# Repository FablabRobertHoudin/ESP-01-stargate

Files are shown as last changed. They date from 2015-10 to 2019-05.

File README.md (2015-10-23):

# Horloge "stargate" avec bandeau LED (WS2812)

- Schéma Kicad

Attention à l'alimentation du ESP2866 qui nécessite + de 200mA au démarrage.

- Programme

Encore en développement.
Récupère l'heure par NTP (OK)
Une couleur peut être envoyée pour affichage ! - en cours, avec utilisation de PubNub

- Le modèle

Réalisé en médium 3mm.
La face avant avec les chiffres + 3 épaisseurs collées réalisées en 4 morceaux (asymétriques alternées)
Le bandeau (largeur 1cm) est colé à l'arrière de la face avant, sur les 3 épaisseurs arrière.

Initialement, je voulais le créer à partir d'une découpe d'un STL (crée à partir de openSCAD) par 123Make.
Mais les morceaux n'étaient pas compactés (voir le PDF)
J'ai donc arrangé les morceaux (tranchage dans openSCAD) à la main (stargate-pack.svg) pour optimiser la découpe du médium 3mm.

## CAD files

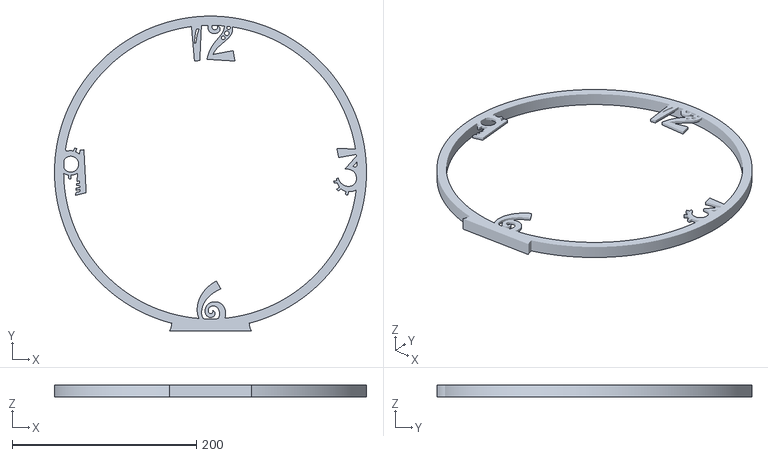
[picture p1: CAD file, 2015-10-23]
Modèle/Stargate.stl
338.3 x 341.3 x 13.0

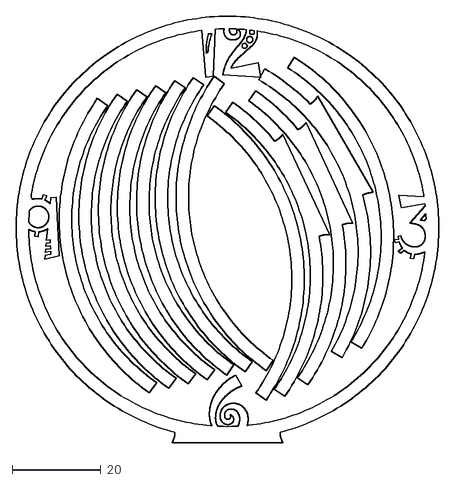
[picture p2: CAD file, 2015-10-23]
Modèle/stargate-pack.dxf
95.5 x 96.3

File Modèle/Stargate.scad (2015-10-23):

// Unité: mm
R = 1000/3.141592/2;
fn = 300;
sf = 40;

//color([0,1,0])cube([318,20,20], center=true);

projection(cut = true)
  translate([0,0,-0]) // -4 pour dessus, 0 dessous
  horloge();

module horloge(){
// Rond externe
 translate([0,0,-7])
 difference(){
  rond();
  color([0.9,0,0])cylinder(h=13, r=R, $fn=fn);
  rotate(a=30)translate([0,0,5])color([0,0,1])cube([900,0.1,10], center=true);
  rotate(a=30+90)translate([0,0,5])cube([900,0.1,10], center=true);
 }

 // lettres
 add("3", 0.95, 0);
 add("6", 0, -0.9);
 add("9", -0.95, 0);
 add("12", 0, 0.9);
}

module rond(){
 cylinder(h=13, r=R+10, $fn=fn); // 1cm d'épaisseur
 // base
 translate([0,-R-4,8.5])
 scale([3,3,1])difference(){
  translate([  0,0,-2]) cube([30,6,13], center=true);
  translate([+20,0,-10]) cylinder(h=20, r=6, $fn=fn);
  translate([-20,0,-10]) cylinder(h=20, r=6, $fn=fn);
  }
}

module add(txt, dx, dy) {
  translate([R*dx, R*dy, 3])
  linear_extrude(height=3, convexity=4)
  text(txt, 
    size=sf,
    font="Jokerman",
    halign="center",
    valign="center", $fn=fn);
}

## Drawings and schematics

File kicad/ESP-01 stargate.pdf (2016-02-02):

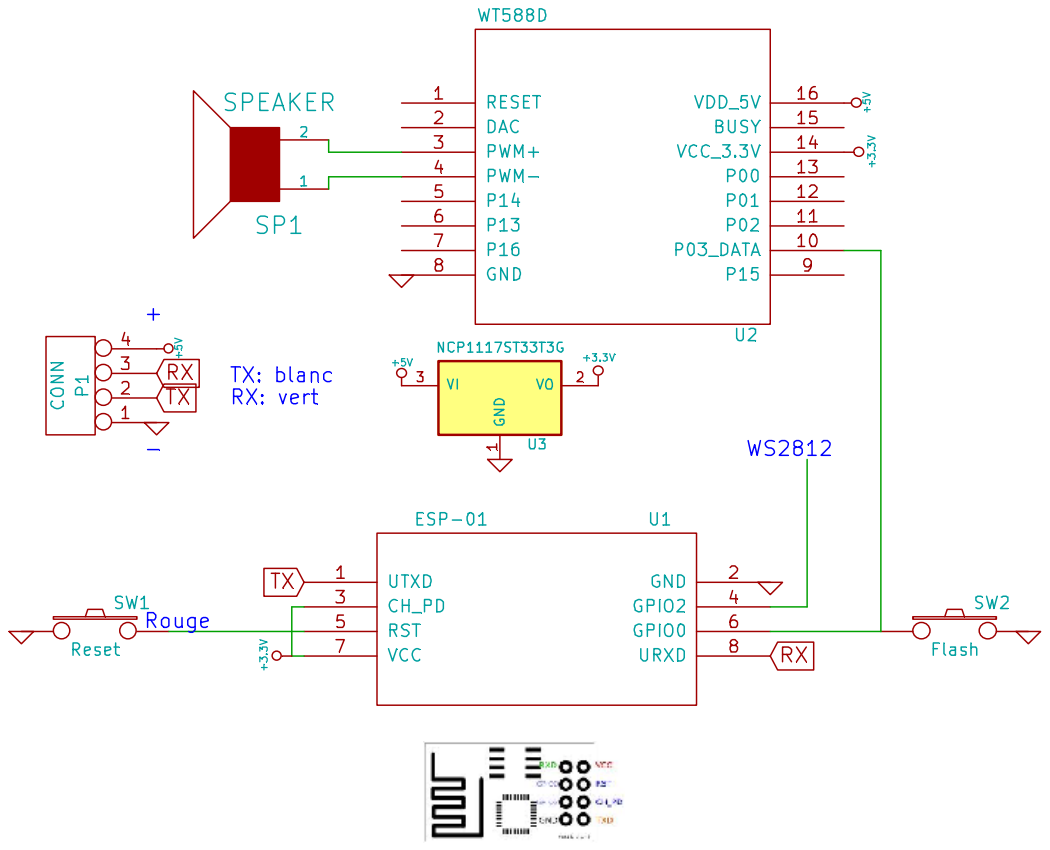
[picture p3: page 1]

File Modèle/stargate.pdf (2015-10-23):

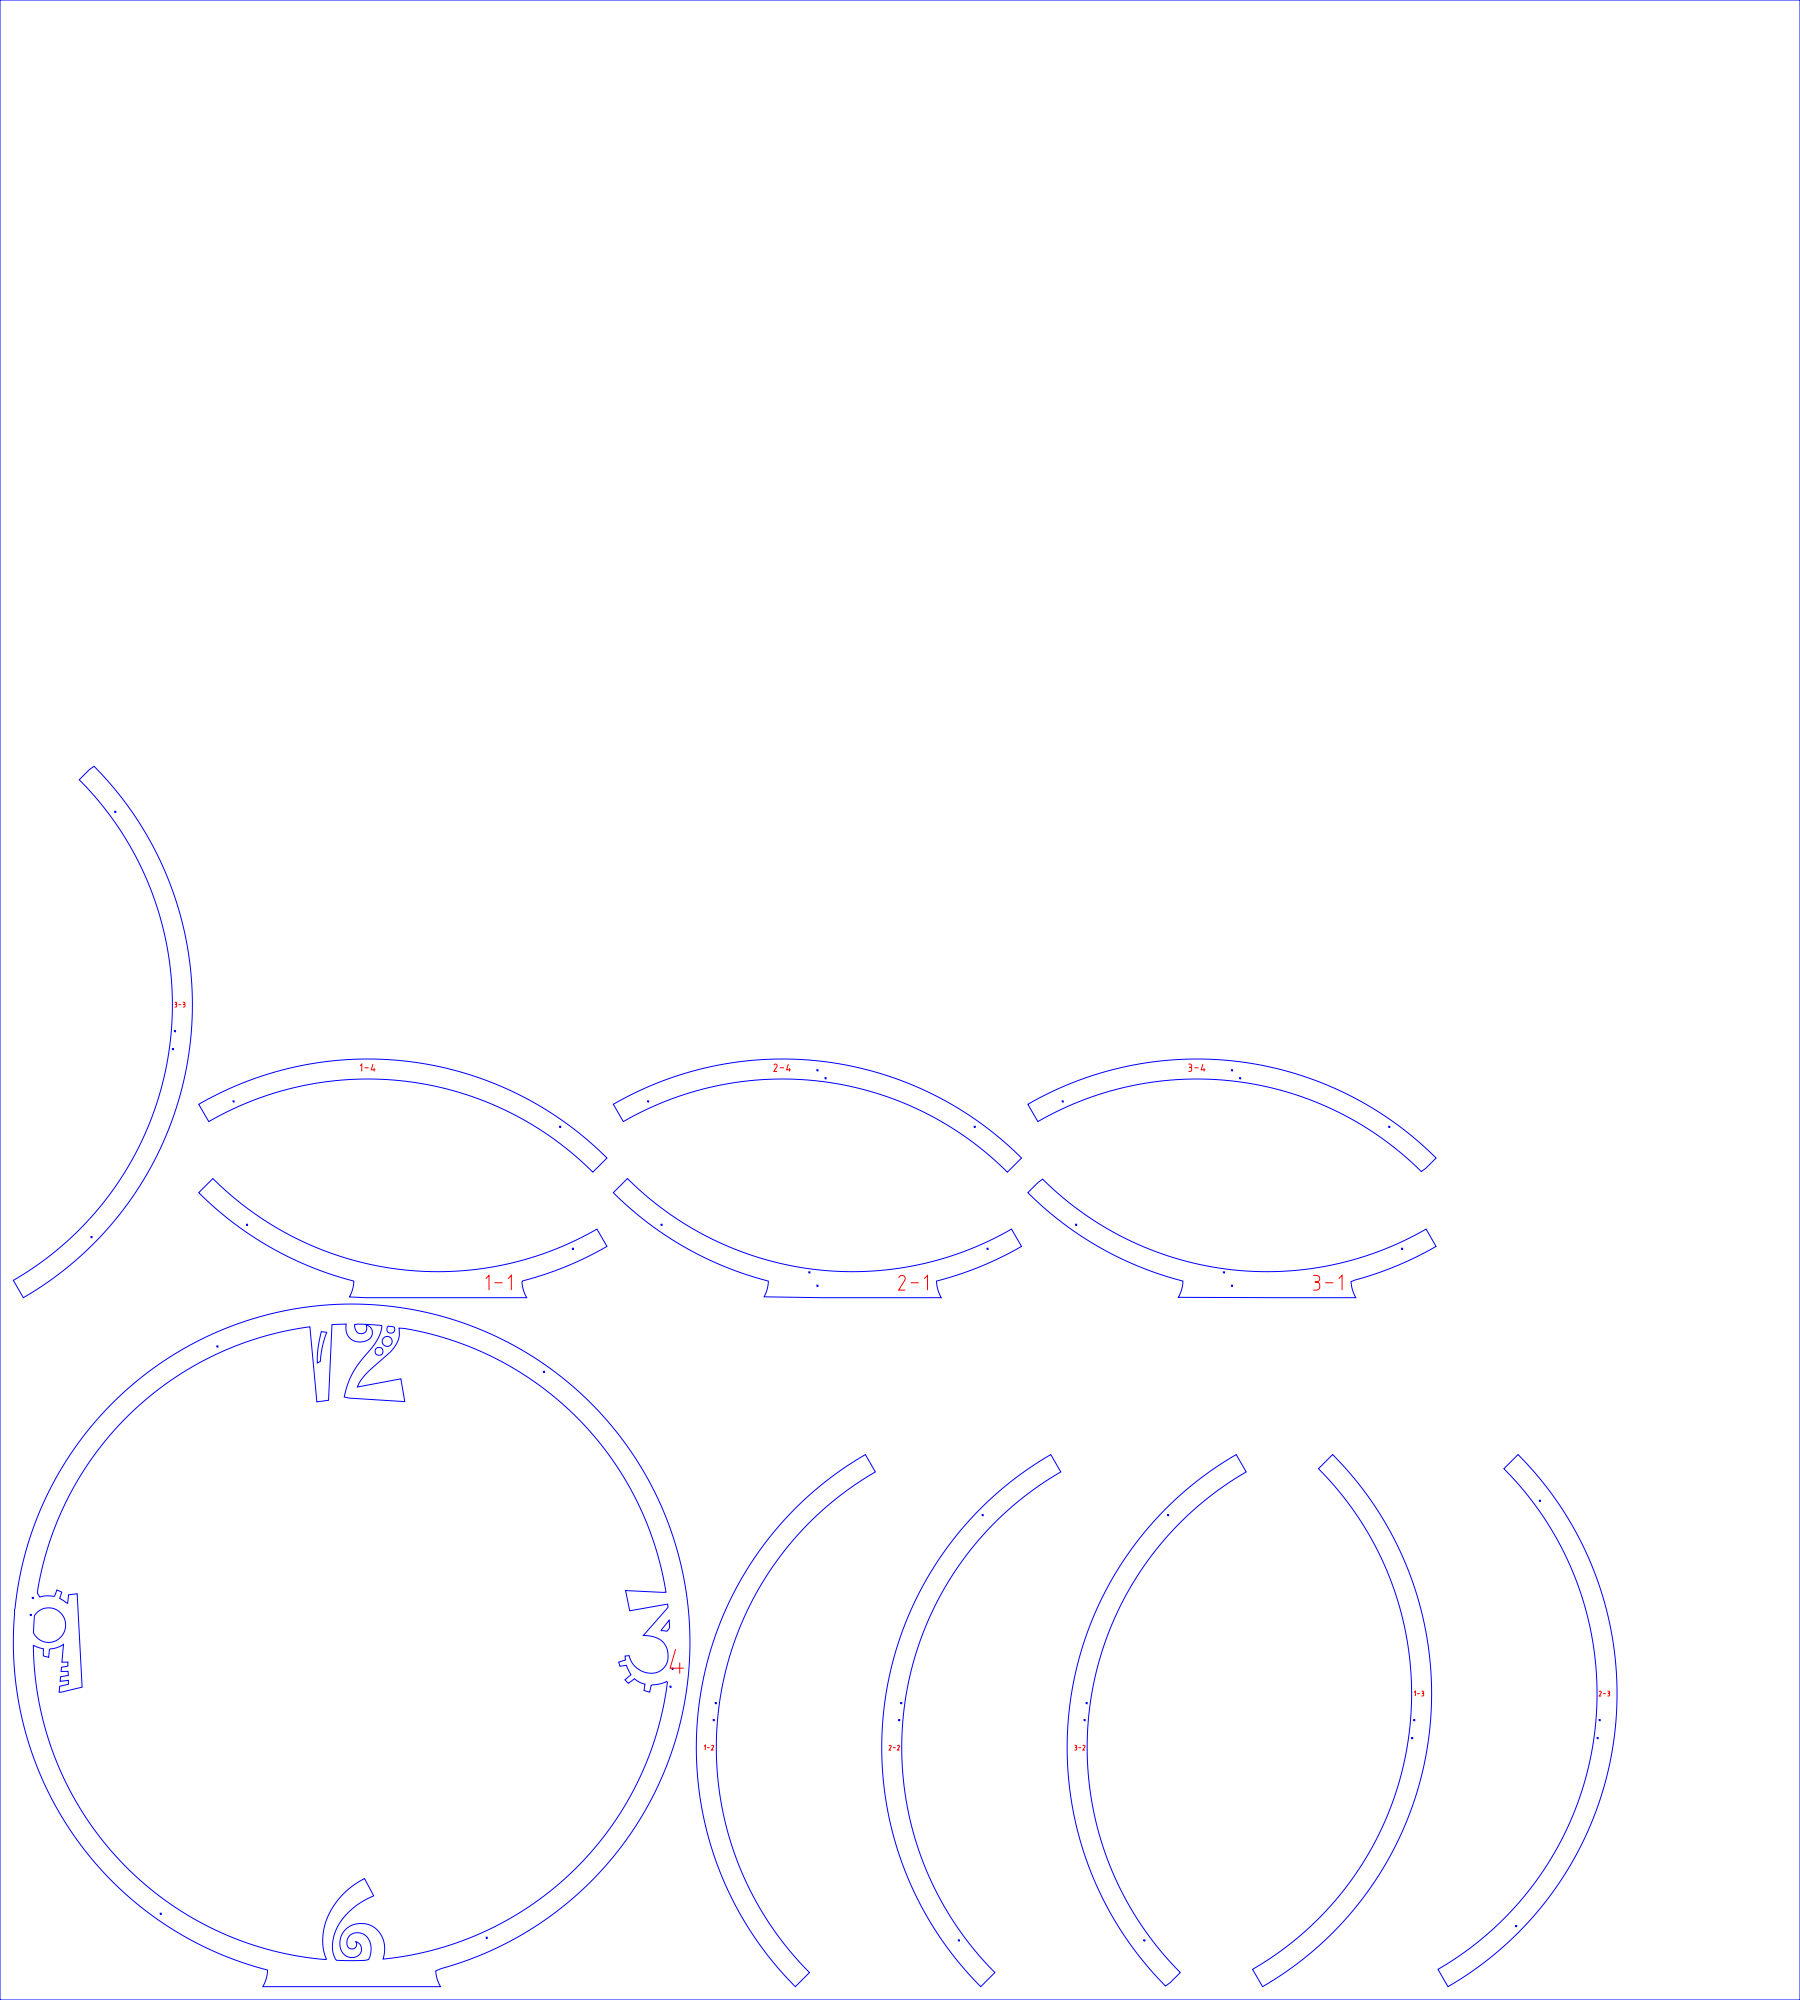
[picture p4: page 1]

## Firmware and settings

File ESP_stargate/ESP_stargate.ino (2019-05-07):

#include "ESP8266WiFi.h"
#include <Ticker.h>
#include <WiFiUdp.h>
//#include <EEPROM.h>

//needed for library
#include <DNSServer.h>
#include <ESP8266WebServer.h>
#include <WiFiManager.h>          //https://github.com/tzapu/WiFiManager WiFi Configuration Magic

// https://www.tala-informatique.fr/wiki/index.php/Esp8266_ntp_client
#include <TimeLib.h>
#include <NtpClientLib.h>

#include <FastLED.h>

// https://projetsdiy.fr/esp-01-esp8266-flasher-firmware-origine/
#define LED_PIN     2 // côté GND
#define NUM_LEDS    12
#define BRIGHTNESS  64
#define LED_TYPE    WS2811
#define COLOR_ORDER GRB
CRGB leds[NUM_LEDS];


// Serveur NTP
const char ntpServer[] = "pool.ntp.org";
// Offset depuis UTC
int8_t timeZoneOffset = 0;
// Le fuseau utilise les horaires été / hiver
bool dayligthSaving = true;
// Minutes d'offset à ajouter
int8_t minutesOffset = 0;

/*
 * 20/09/2015: strips added
 * 15/10/2015: NTP;h
 * 15/01/2016: added storage to flash (http://www.esp8266.com/viewtopic.php?f=34&t=2662)
 * 
 */

//#include "NTP.h"
//#include "Strip.h"
//#include "PubNub.h"

//#define CONFIG_SECTOR 0x80-4
//#define CONFIG_ADDRESS (CONFIG_SECTOR * SPI_FLASH_SEC_SIZE)

extern const char* pubKey;
extern const char* subKey;

WiFiServer server(80);

Ticker tick;

//PubNub pubnub(pubKey, subKey);

//#define GRBpin 2
#define WT588pin 0

//byte GRB[3 * LEN];
//Strip *sStrip, *mStrip, *hStrip, *waitStrip;

// ====================================================================================================

void setup() {
  int loop = 0, i=0;

  FastLED.addLeds<LED_TYPE, LED_PIN, COLOR_ORDER>(leds, NUM_LEDS).setCorrection( TypicalLEDStrip );

  Serial.begin(115200);
  Serial.flush();

  //WiFiManager
  //Local intialization. Once its business is done, there is no need to keep it around
  WiFiManager wifiManager;

  //exit after config instead of connecting
  //wifiManager.setBreakAfterConfig(true);

  //tries to connect to last known settings
  //if it does not connect it starts an access point with the specified name
  //here  "AutoConnectAP" with password "password"
  //and goes into a blocking loop awaiting configuration
/*
  if (!wifiManager.autoConnect("stargateAP", "Goudot")) {
    Serial.println("failed to connect, we should reset as see if it connects");
    delay(3000);
    ESP.reset();
    delay(5000);
  }
*/
  wifiManager.startConfigPortal("stargateAP");

  //pinMode(GRBpin, OUTPUT); digitalWrite(GRBpin, LOW);
  pinMode(WT588pin, OUTPUT); digitalWrite(WT588pin, HIGH);

  // Print the IP address
  IPAddress ip = WiFi.localIP();
  Serial.println(ip);
  //Serial.end();

  // Démarrage du processus NTP
  NTP.begin (ntpServer, timeZoneOffset, dayligthSaving, minutesOffset);
  // Interval de synchronisation en seconde (30 min.)
  NTP.setInterval (1800);

  //Ntp.sendNTPpacket(NTP::timeServer); // send an NTP packet to a time server
/*
  sStrip = new Strip(5, "SS"); sStrip->fill( 16,   0,  16); // sec
  mStrip = new Strip(1, "MM"); mStrip->fill(255,   0,   0); // min RED
  hStrip = new Strip(1, "HH"); hStrip->fill(255, 255, 255); // hour WHITE
  
  waitStrip = new Strip(20, "wait");
*/

  server.begin();
  Serial.println("Server started");

//  pubnub.publish("Stargate", "\"Started !\"");

  tick.attach(0.5, updateTime);
  //tick.attach(0.1, updateTime);
}

void printTime(){
  static uint16_t i = 0;
  Serial.printf ("%d %s ", i, NTP.getTimeDateString ().c_str());
  Serial.print (NTP.isSummerTime () ? "Heure d'été. " : "Heure d'hiver. ");
  Serial.printf ("Démarrage le: %s allumé depuis %s\n", NTP.getTimeDateString(NTP.getFirstSync()).c_str(), NTP.getUptimeString().c_str());
  i++;
  delay(5000);
}

void processNtpEvent (NTPSyncEvent_t ntpEvent) {
  if (ntpEvent) {
    Serial.print ("Erreur de synchronisation: ");
    if (ntpEvent == noResponse)
      Serial.println ("Serveur NTP injoignable");
    else if (ntpEvent == invalidAddress)
      Serial.println ("Adresse du serveur NTP invalide");
  } else {
    Serial.print ("Récupération du temps NTP: ");
    Serial.println (NTP.getTimeDateString (NTP.getLastNTPSync ()));
  }
}


// ----------------------------------------------------------------------------------------------------

void sendWT588(int b) {
  int i;  
    Serial.print("Send WT588D: ");
    Serial.println(b);
  noInterrupts();
  digitalWrite(WT588pin, LOW);
  delay(5); // ms
  for (i = 0; i < 8; i++) {
      if (b & 0x01) { // bit 1
        digitalWrite(WT588pin, HIGH); // 4 HIGH 1 LOW ?
        delayMicroseconds(400);
        digitalWrite(WT588pin, LOW);
        delayMicroseconds(200);
      } else { // bit 0
        digitalWrite(WT588pin, HIGH); // 1 HIGH 4 LOW ?
        delayMicroseconds(200);
        digitalWrite(WT588pin, LOW);
        delayMicroseconds(400);
      }
      b /= 2;
  }
  digitalWrite(WT588pin, HIGH);
  interrupts();
}

// GRB: 0 en bas avec 60, tourne dans le sens trigo...
/*
void displayOLD() {
  byte *ptr = GRB, b;
  int i, j;
  noInterrupts();
  for (i = 0; i < (LEN * 3); i++) {
    b = *ptr++;
    for (j = 0; j < 8; j++) {
      if (b & 0x80) { // bit 1
        digitalWrite(GRBpin, HIGH); // 4 HIGH 1 LOW ?
        digitalWrite(GRBpin, HIGH);
        digitalWrite(GRBpin, HIGH);
        digitalWrite(GRBpin, LOW);
      } else { // bit 0
        digitalWrite(GRBpin, HIGH); // 1 HIGH 4 LOW ?
        digitalWrite(GRBpin, LOW);
        digitalWrite(GRBpin, LOW);
        digitalWrite(GRBpin, LOW);
      }
      b *= 2;
    }
  }
  interrupts();

}
*/
// ----------------------------------------------------------------------------------------------------

int wPos; // Position attente
int wLoop; // nombre de fois qu'on itère
/*
void updateWait() {
  waitStrip->writeGRB(wPos++);

  display();

  if (--wLoop == 0) { // finished
    tick.attach(0.5, updateTime);
  }
}
*/
// ----------------------------------------------------------------------------------------------------

void updateTime() {
  //byte *ptr, b, v;
  int i;
  static int _m;
/*
  Ntp.update();

  Serial.print(Ntp._h);
  Serial.print(":");
  Serial.print(Ntp._m);
  Serial.print(":");
  Serial.print(Ntp._s);
  Serial.print("\n");

  if (Ntp._s==0 && (Ntp._m != _m)) {
    _m = Ntp._m;
    if (Ntp._m == 15) sendWT588(13);
    if (Ntp._m == 30) sendWT588(14);
    if (Ntp._m == 45) sendWT588(15);
    if (Ntp._m == 0) sendWT588(Ntp._h % 12);
  }
*/

/*
  Serial.print("Time: ");
  Serial.print(Ntp._h);
  Serial.print(":");
  Serial.print(Ntp._m);
  Serial.print(":");
  Serial.print(Ntp._s);
  Serial.println();
*/

/*
  // clear GRB
  memset(GRB, 0, LEN * 3);

  sStrip->writeGRB(Ntp._s); // +LEN - 5
  mStrip->writeGRB(Ntp._m);
  hStrip->writeGRB((Ntp._h % 12) * 60 / 12);
  //memcpy(GRB + 59 * 3, "\x00\x00\xFF", 3); // last: BLUE

  display();
*/
}

// ----------------------------------------------------------------------------------------------------

unsigned long 
tx = 0;

void loop() {
  int code;

  NTP.onNTPSyncEvent ([](NTPSyncEvent_t event) {
    processNtpEvent(event);
  });
  
  printTime();
/*
  if (!Ntp.parsed) {
    Ntp.checkPacket();
    // Start the server
  }
*/
  if (millis() - tx > 20000) {
    tx = millis();
    //String line = pubnub.subscribe("Stargate");
    //Serial.println("ESP subscribe: " + line);
    
  }


  WiFiClient client = server.available();
  if (client) {
    // Wait until the client sends some data
    //Serial.println("new client");
    while (!client.available()) {
      delay(1);
    }

    // Read the first line of the request
    String req = client.readStringUntil('\r');
    Serial.println("REQ: " + req);
    client.flush();

    // GET /?color=%23ff0000&speed=5
    int idx = req.indexOf("color=");
    int idxc = req.indexOf("speed=");

    // Send the response to the client
    client.print("HTTP/1.1 200 OK\r\nContent-Type: text/html\r\n\r\n<!DOCTYPE HTML>\r\n<html>");
    client.print("<head><title>Stargate</title></head>");
    client.print("<h3>Stargate</h3>my time: ");
/*
    Ntp.update();
    client.print(Ntp._h);
    client.print(":");
    client.print(Ntp._m);
    client.print(":");
    client.print(Ntp._s);
*/
    client.print("<br/><form method='GET'>");
    client.print("Couleur: <input type='color' name='color' value='#" + req.substring(idx + 9, idx + 15) + "' onchange='this.form.submit()'><br/>");
    //client.print("Vitesse: <input type='range' name='speed' min='0' max='9' value='"+req.substring(idxc+6, idxc+7)+"'><br/>");
    //client.print("<input type='submit'></form>");
    client.print("</html>");
    //client.close();

    if (idx > 0) {

      wPos = 0; // départ
      wLoop = 5 * 60; // X tours
      byte a, b;
      a = req.charAt(idx + 9);
      a = (a > '9') ? a - 'a' + 10 : a - '0';
      b = req.charAt(idx + 10);
      b = (b > '9') ? b - 'a' + 10 : b - '0';
      byte wR = a * 16 + b;
      a = req.charAt(idx + 11);
      a = (a > '9') ? a - 'a' + 10 : a - '0';
      b = req.charAt(idx + 12);
      b = (b > '9') ? b - 'a' + 10 : b - '0';
      byte wG = a * 16 + b;
      a = req.charAt(idx + 13);
      a = (a > '9') ? a - 'a' + 10 : a - '0';
      b = req.charAt(idx + 14);
      b = (b > '9') ? b - 'a' + 10 : b - '0';
      byte wB = a * 16 + b;
      //wG = atoi("0x"+req.substring(idx+9, idx+11));
      //wB = atoi("0x"+req.substring(idx+11, idx+13));
      Serial.print("wR=");
      Serial.print(wR, HEX);
      Serial.print(", wG=");
      Serial.print(wG, HEX);
      Serial.print(", wB=");
      Serial.print(wB, HEX);
      Serial.println();
/*
      wPos = 0; // départ
      wLoop = 10 * 60; // X tours
      waitStrip->fill(wR, wG, wB, 0);
      tick.attach(0.01, updateWait);
*/
    }

  } // if client


  if (Serial.available()) {
    code = Serial.parseInt();
/*
    while (Serial.available()) {
      Serial.read();
    }
*/
    sendWT588(code);
/*
    wPos = 0; // départ
    wLoop = 10 * 60; // X tours
    waitStrip->fill(0, 0, 255, 0);
    tick.attach(0.001, updateWait);
*/
  }
  /*
    if (millis() - tx > 20000) {
      tx = millis();
      wPos = 0; // départ
      wLoop = 10 * 60; // X tours
      waitStrip->fill(0, 100, 255, 0);
      tick.attach(0.001, updateWait);
    }
  */

}

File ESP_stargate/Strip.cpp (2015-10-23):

#include "Strip.h"
    
    Strip::Strip(int len, String name) {
        _len = len;
        _name = name;
        data = (byte*)malloc(3*len);
        //Serial.println("new strip '"+_name+"'"); Serial.print("malloc: "); Serial.println((int)data);
      }

    void Strip::resize(int len) {
      data = (byte*)realloc(data, 3*len);
    }

    void Strip::fill(byte wR, byte wG, byte wB, int start) { // start=1: no zero start=0
      byte *ptr = data;
      Serial.println("strip '"+_name+"' filling");
      for (int i = 0; i < _len; i++) {
        *ptr++ = (byte) (wG * start / _len) & 0xFF;
        *ptr++ = (byte) (wR * start / _len) & 0xFF;
        *ptr++ = (byte) (wB * start / _len) & 0xFF;
        start++;
      }
    }
    
    void Strip::writeGRB(int pos, int offset) { // write to data !
      pos = 90 - pos; // compensation position
      while (pos<0) pos += LEN;
      while (pos >= LEN) pos -= LEN;
      //Serial.print("writeGRB "); Serial.println(pos);
      int l = _len - offset;
      int last = pos + l; // last position
      if (last < LEN) { // OK one write
        memcpy(GRB+(pos*3), data+(offset*3), l*3);
      } else {
        int n1 = LEN-pos;
        memcpy(GRB+(pos*3), data+(offset*3), n1*3);
        memcpy(GRB, data+((offset+n1)*3), (l-n1)*3);
      }
    }

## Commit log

2015-10-23 Creation
    Ajout fichiers Kicad et sources
2015-10-23 Modèle added
    Ajout des info sur le modèle (découpe laser)
    [Stargate.scad, Stargate.stl, stargate-pack.dxf]
2015-10-30 Corrections
    Ajout de (no)interrupts en particulier
    Fichier config.c doit definir pubKey, subKey, ssid1/2 et password1/2
    [ESP_stargate.ino]
2016-02-07 INO correction
    Avoid calling twice sendWT588()
    [ESP_stargate.ino]
2019-05-07 Utilise les librairies importées Utilise fastLED
